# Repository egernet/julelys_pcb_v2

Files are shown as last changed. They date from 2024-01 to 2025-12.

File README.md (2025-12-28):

# Julelys PCB v3

HAT (Hardware Attached on Top) til Orange Pi Zero 2 til styring af adresserbare SK6812 RGBW LED-strips.

## System Oversigt

```
Orange Pi Zero 2 ──► Julelys HAT ──► 8×55 SK6812 LED Matrix (440 LEDs)
        │                 │
        │ SPI @ 2.5 Mbps  │
        ▼                 ▼
  julelys_manager    ESP32-C3 (SPI slave)
                          │
                          ▼
                    74HC4051 MUX + Level Shifters
                          │
                          ▼
                    8x JST outputs
```

## Relaterede Repositories

| Repository | Beskrivelse |
|---|---|
| [julelys_manager](https://github.com/egernet/julelys_manager) | Swift CLI + MCP server til LED-styring |
| [julelys_esp32](https://github.com/egernet/julelys_esp32/tree/feature/Hat) | ESP-IDF firmware (feature/Hat branch) |

## Features

- **ESP32-C3-WROOM-02** som SPI slave med RMT LED driver
- **8 LED-kanaler** via 74HC4051 multiplexer
- **Level shifting** (3.3V → 5V) via 74AHCT1G125
- **USB-C** til strøm og programmering (CP2102N)
- **Auto-reset** kredsløb til nem flashing
- **AI-styring** via Model Context Protocol (MCP)

## Nøglekomponenter

| Komponent | Funktion |
|---|---|
| ESP32-C3-WROOM-02 | Hoved-MCU, SPI slave |
| CP2102N | USB-UART bridge |
| AMS1117-3.3 | 5V → 3.3V LDO |
| 74HC4051 | 8-kanal analog multiplexer |
| 74AHCT1G125 ×4 | Level shifters |

## Connectors

| Reference | Type | Funktion |
|---|---|---|
| J1 | 2×13 Pin Socket | Orange Pi GPIO header |
| J4-J11 | JST B3B-XH-A ×8 | LED strip outputs |
| P1 | USB-C | Strøm + programmering |
| V_IN1 | Skrueterminal | Ekstern 5V |

## KiCad Filer

- `Julelys.kicad_pcb` - PCB layout
- `Julelys.kicad_sch` - Hovedskema
- `esp32.kicad_sch` - ESP32 subskema
- `power.kicad_sch` - Strømforsyning
- `untitled.kicad_sch` - USB-C og connectors

## Produktion

Produktionsfiler genereres til `production/`:
- Gerber filer (zipped)
- `bom.csv` - Stykliste
- `positions.csv` - Pick and place

## Licens

MIT

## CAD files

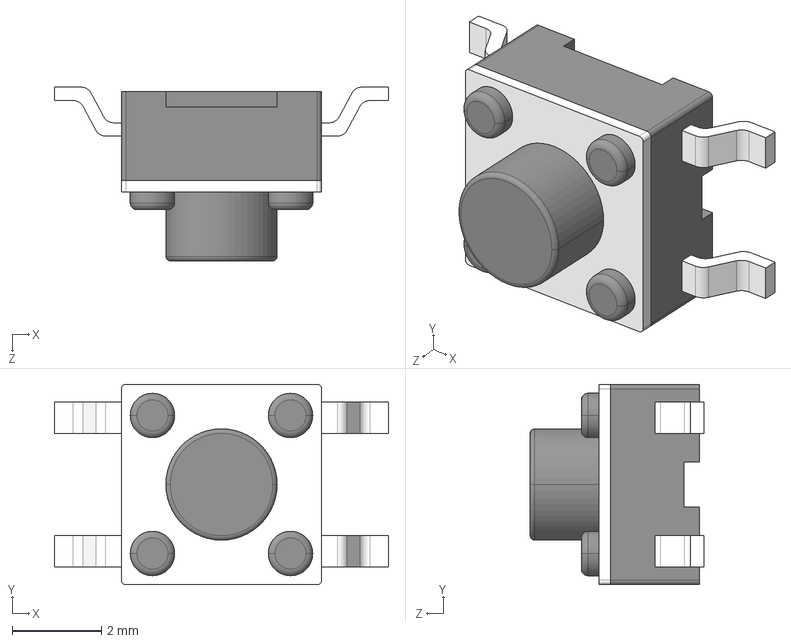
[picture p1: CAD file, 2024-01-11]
3D/TL3305AF260QG.stp
7.50 x 4.50 x 3.90 mm

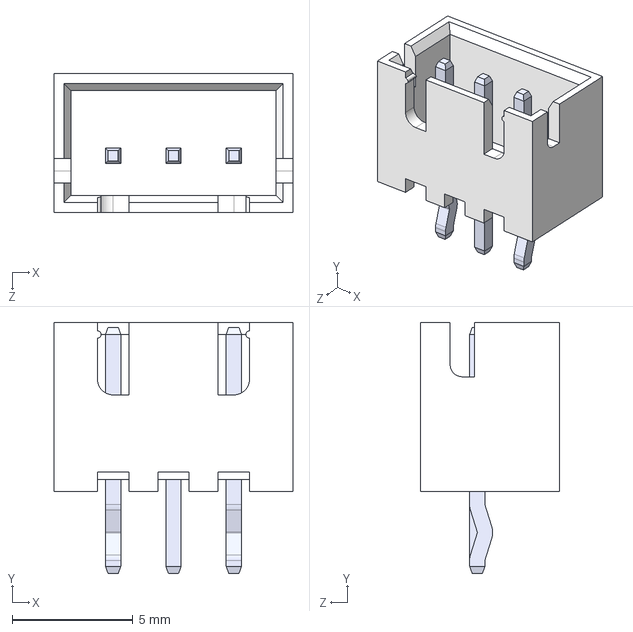
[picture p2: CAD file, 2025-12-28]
B3B_XH_A/B3B-XH-A.step
9.90 x 10.4 x 5.75 mm

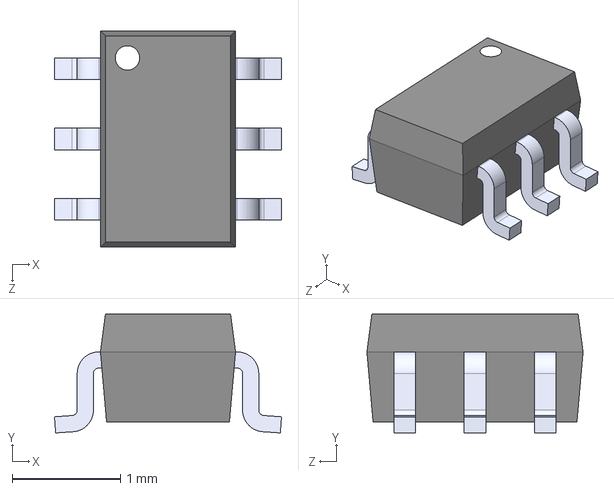
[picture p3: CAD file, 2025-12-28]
BC847BDW1T1G/BC847BDW1T1G.step
2.10 x 1.10 x 2.00 mm

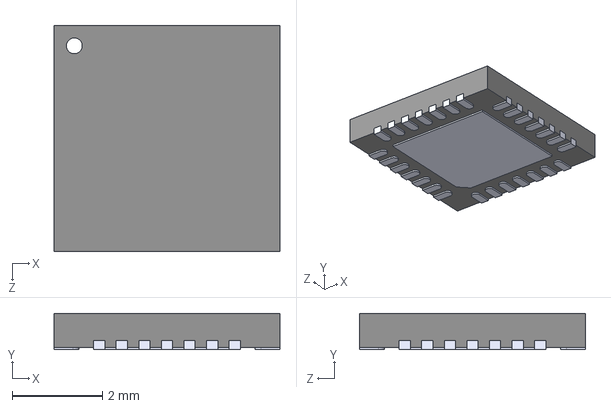
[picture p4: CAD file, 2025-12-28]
CP2102N_A02_GQFN28/CP2102N-A02-GQFN28.step
5.00 x 0.8 x 5.00 mm

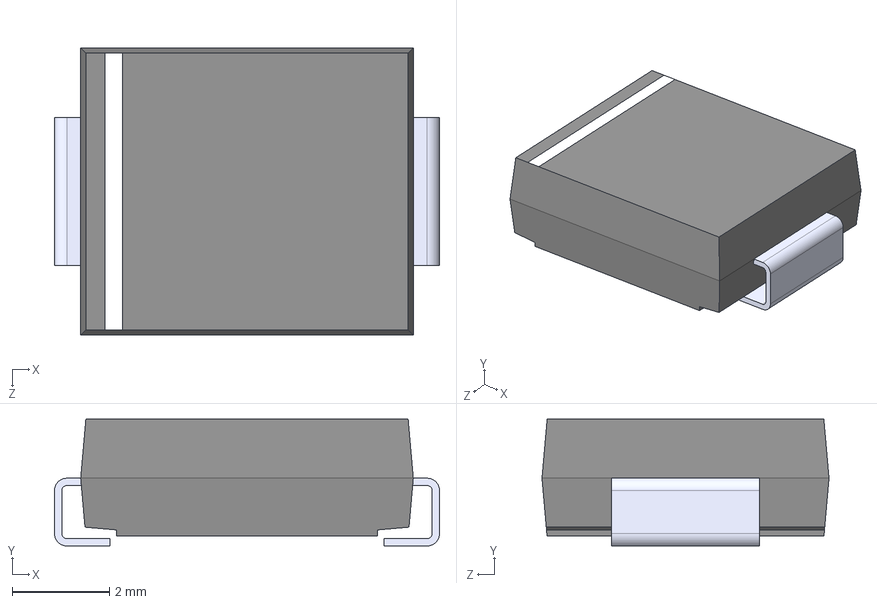
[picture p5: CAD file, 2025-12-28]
SS34_E3_57T/SS34-E3_57T.step
7.94 x 2.62 x 5.92 mm

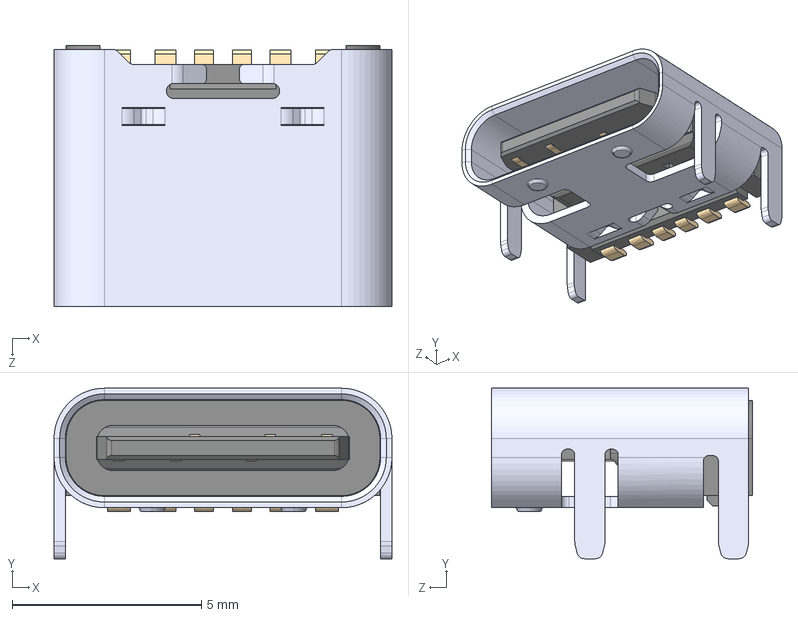
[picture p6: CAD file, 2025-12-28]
USB4125_GF_A/USB4125-GF-A_REVA2.step
8.94 x 4.51 x 6.90 mm

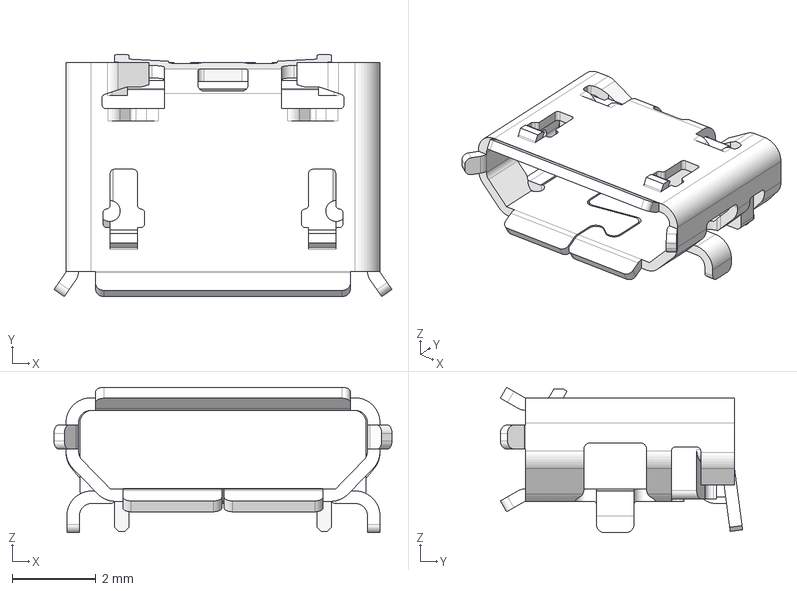
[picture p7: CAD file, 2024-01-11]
ZX62D_B_5PA8/ZX62D-B-5PA8.step
8.09 x 5.80 x 3.48 mm

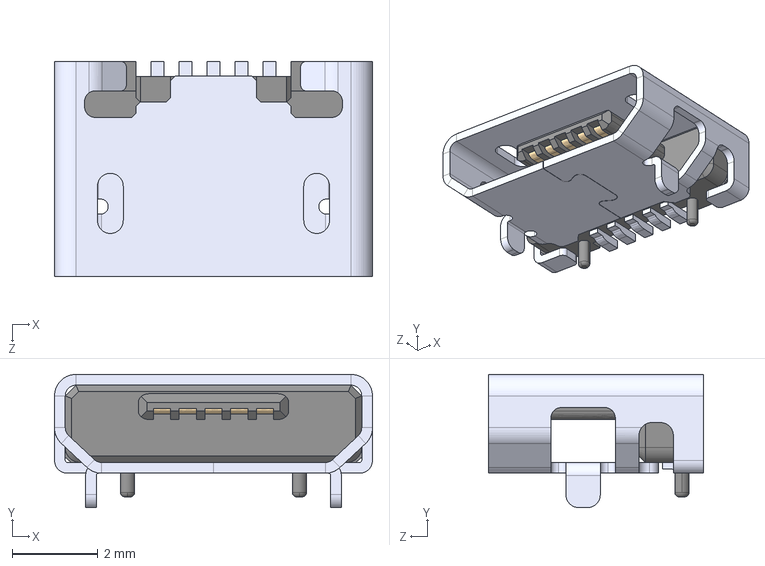
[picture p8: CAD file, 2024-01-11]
3D/U254-051T-4BH83-F1S--3DModel-STEP-510211.STEP
7.40 x 3.10 x 5.00 mm

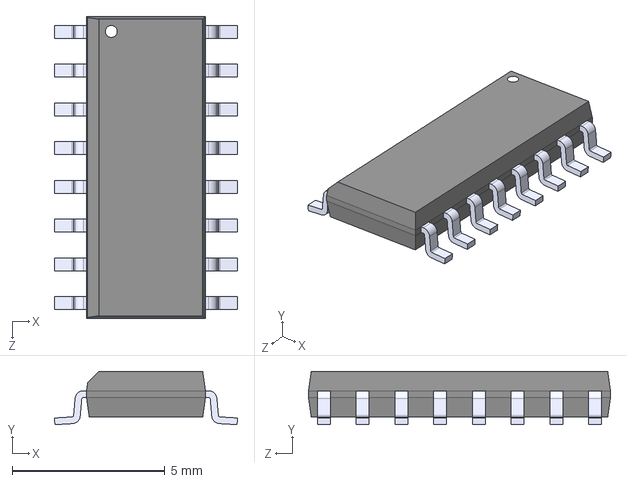
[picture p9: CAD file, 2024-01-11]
3D/74HC4051D.STEP
6.00 x 1.75 x 9.90 mm

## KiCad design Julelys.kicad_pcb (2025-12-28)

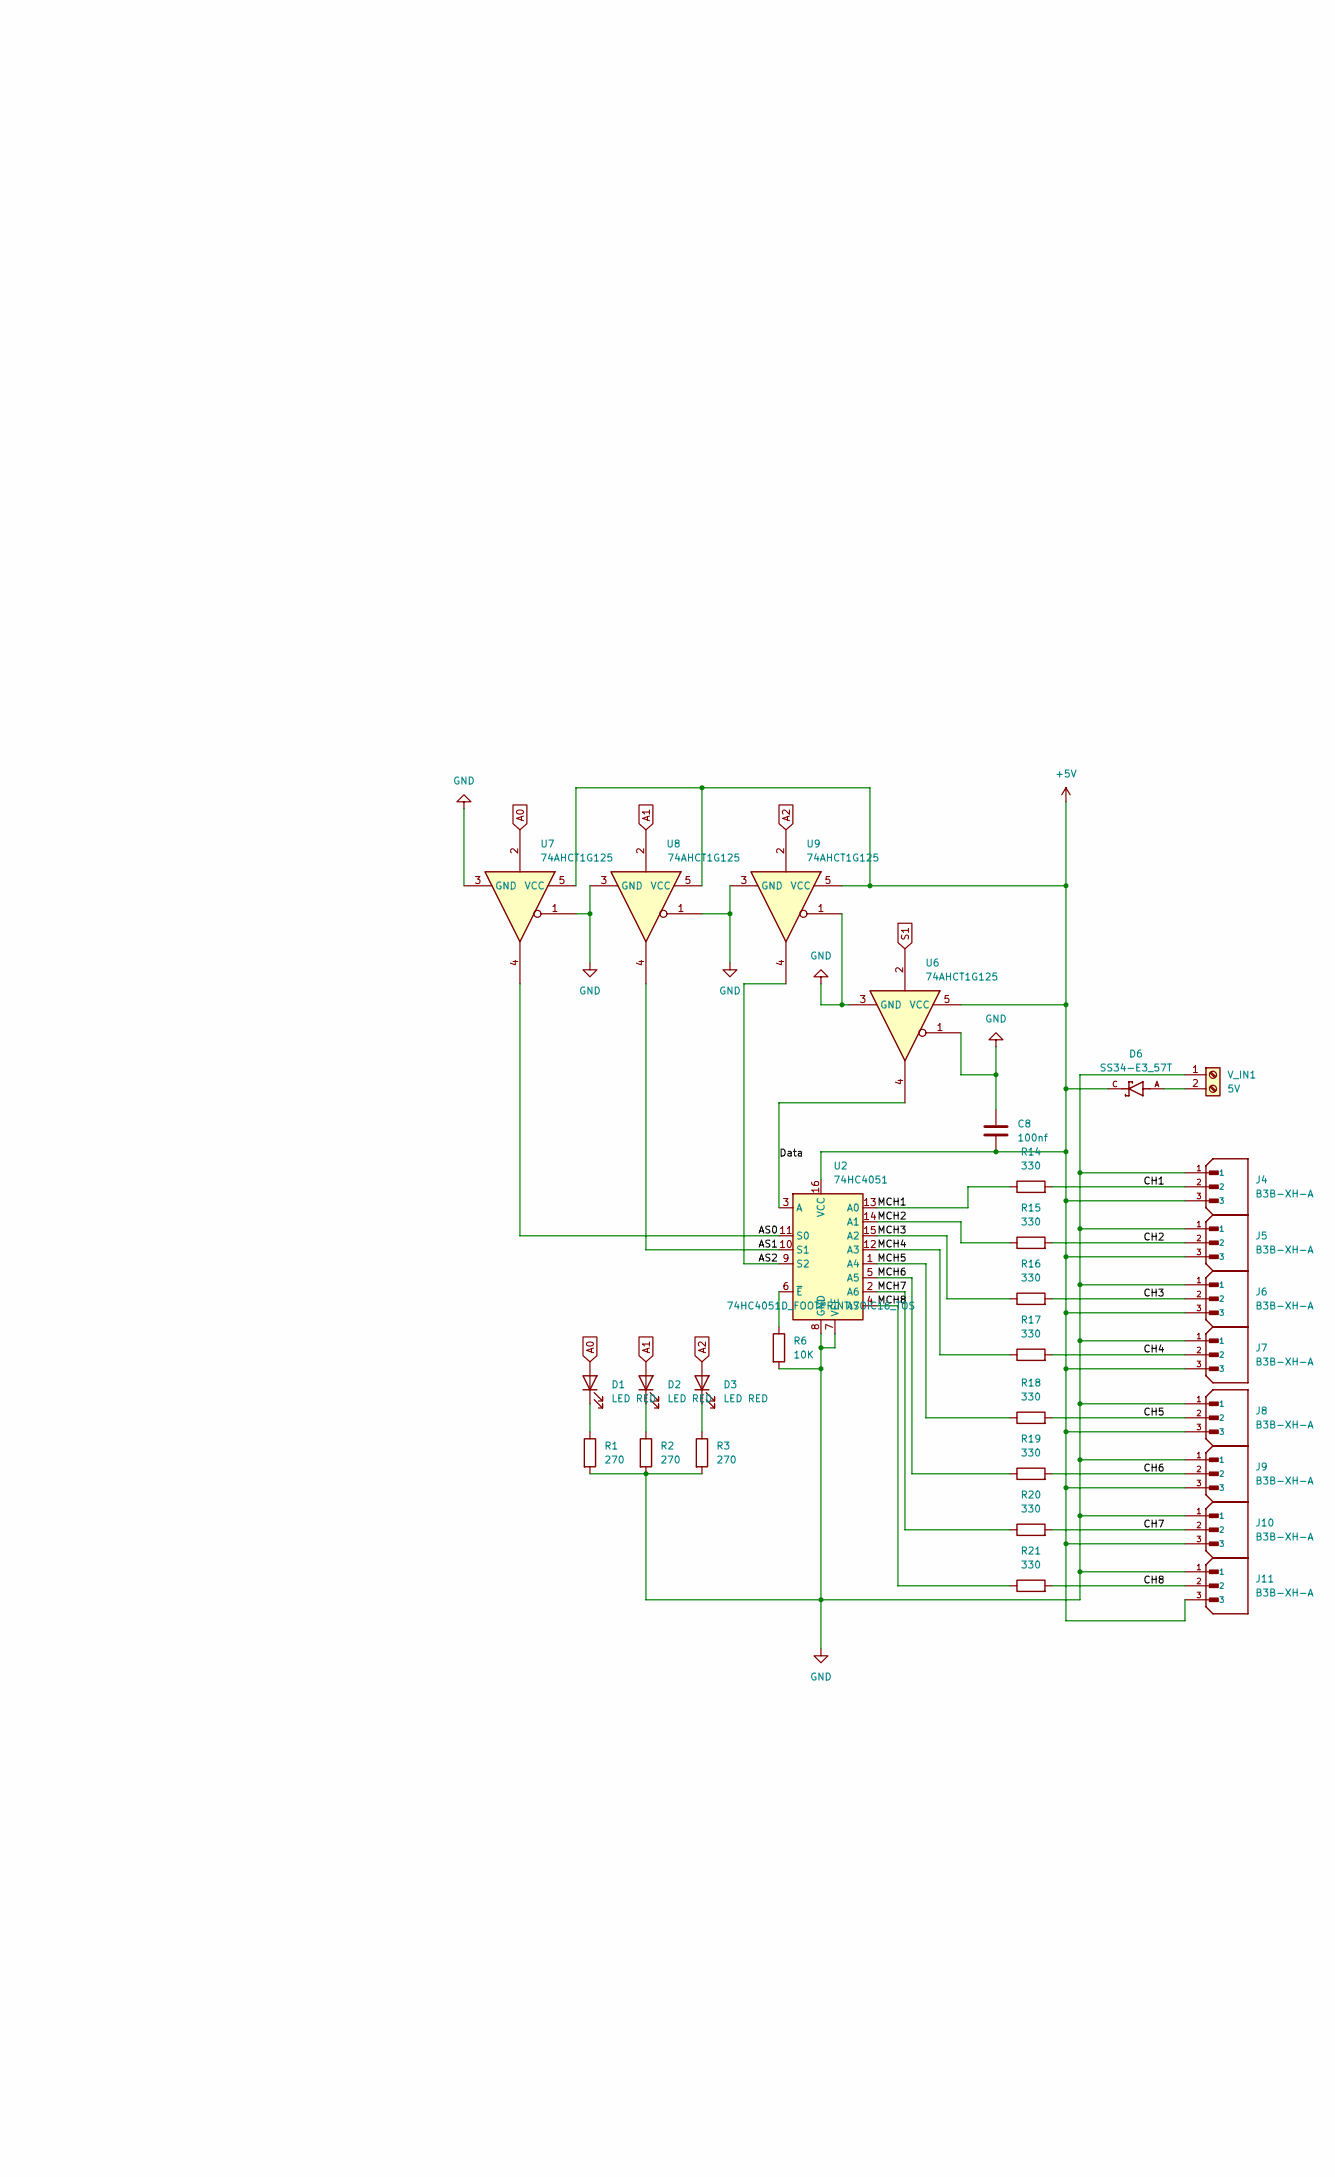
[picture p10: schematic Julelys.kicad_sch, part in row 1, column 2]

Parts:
C8: 100nf; R_0603_1608Metric
D1, D2, D3: LED RED; LED_0805_2012Metric
D6: SS34-E3_57T; DIOM7959X262N; PARTREV N/A
J4, J5, J6, J7, J8, J9, J10, J11: B3B-XH-A; JST_B3B-XH-A; PARTREV 7/4/21
R1, R2, R3: 270; R_0603_1608Metric
R6: 10K; R_0603_1608Metric
R14, R15, R16, R17, R18, R19, R20, R21: 330; R_0603_1608Metric
U2: 74HC4051; SOIC16_TOS
U6, U7, U8, U9: 74AHCT1G125; SOT-353_SC-70-5
V_IN1: 5V; TerminalBlock_Altech_AK300-2_P5.00mm

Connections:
+5V: C8.2, D6.C, J4.3, J5.3, J6.3, J7.3, J8.3, J9.3, J10.3, J11.3, U2.16 (VCC), U6.5 (VCC), U7.5 (VCC), U8.5 (VCC), U9.5 (VCC); also elsewhere on the board
/AS0: U2.11 (S0), U7.4
/AS1: U2.10 (S1), U8.4
/AS2: U2.9 (S2), U9.4
/CH1: J4.2, R14.2
/CH2: J5.2, R15.2
/CH3: J6.2, R16.2
/CH4: J7.2, R17.2
/CH5: J8.2, R18.2
/CH6: J9.2, R19.2
/CH7: J10.2, R20.2
/CH8: J11.2, R21.2
/Data: U2.3 (A), U6.4
/MCH1: R14.1, U2.13 (A0)
/MCH2: R15.1, U2.14 (A1)
/MCH3: R16.1, U2.15 (A2)
/MCH4: R17.1, U2.12 (A3)
/MCH5: R18.1, U2.1 (A4)
/MCH6: R19.1, U2.5 (A5)
/MCH7: R20.1, U2.2 (A6)
/MCH8: R21.1, U2.4 (A7)
A0: D1.2 (A), U7.2; also elsewhere on the board
A1: D2.2 (A), U8.2; also elsewhere on the board
A2: D3.2 (A), U9.2; also elsewhere on the board
GND: C8.1, J4.1, J5.1, J6.1, J7.1, J8.1, J9.1, J10.1, J11.1, R1.2, R2.2, R3.2, R6.2, U2.7 (VEE), U2.8 (GND), U6.1, U6.3 (GND), U7.1, U7.3 (GND), U8.1, U8.3 (GND), U9.1, U9.3 (GND), V_IN1.1; also elsewhere on the board
IO7: U6.2; also elsewhere on the board
unnamed: D1.1 (K), R1.1
unnamed: D2.1 (K), R2.1
unnamed: D3.1 (K), R3.1
unnamed: R6.1, U2.6 (~E)
unnamed: D6.A, V_IN1.2

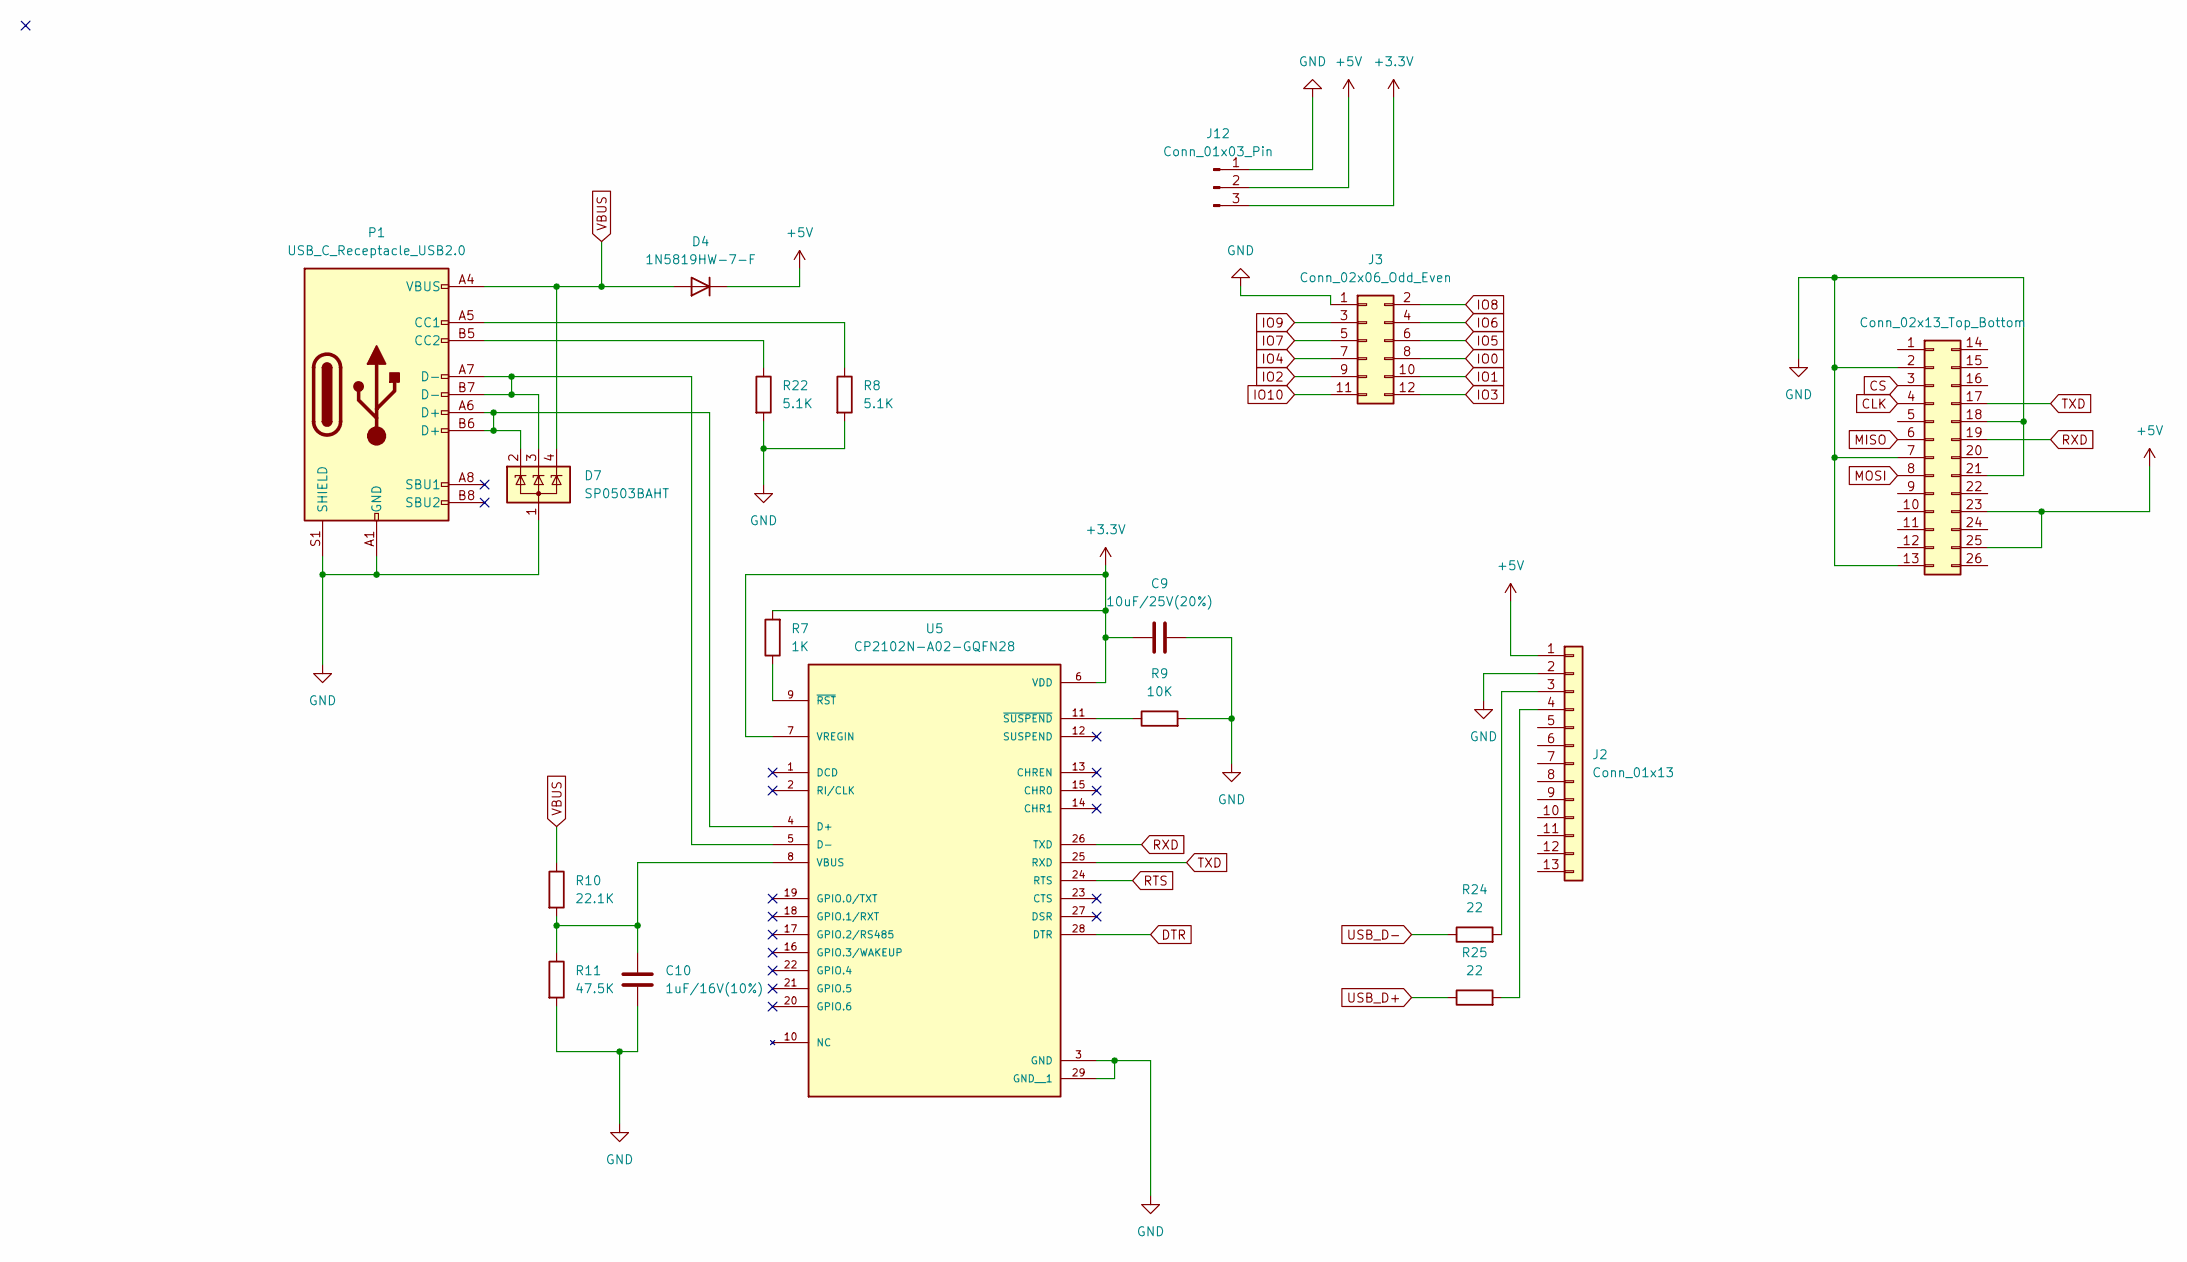
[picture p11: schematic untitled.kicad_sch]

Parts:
C9: 10uF/25V(20%); C_0603_1608Metric
C10: 1uF/16V(10%); C_0603_1608Metric
D4: 1N5819HW-7-F; D_SOD-123
D7: SP0503BAHT; SOT-143
J1: Conn_02x13_Top_Bottom; PinSocket_2x13_P2.54mm_Vertical
J2: Conn_01x13; PinSocket_1x13_P2.54mm_Vertical
J3: Conn_02x06_Odd_Even; PinHeader_2x06_P2.54mm_Vertical
J12: Conn_01x03_Pin; PinHeader_1x03_P2.54mm_Vertical
P1: USB_C_Receptacle_USB2.0; USB_C_Receptacle_HRO_TYPE-C-31-M-12
R7: 1K; R_0603_1608Metric
R8, R22: 5.1K; R_0603_1608Metric
R9: 10K; R_0603_1608Metric
R10: 22.1K; R_0603_1608Metric
R11: 47.5K; R_0603_1608Metric
R24, R25: 22; R_0603_1608Metric
U5: CP2102N-A02-GQFN28; QFN50P500X500X80-29N; PARTREV 1.5

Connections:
+3.3V: C9.1, J12.3, R7.2, U5.6 (VDD), U5.7 (VREGIN); also elsewhere on the board
+5V: D4.1 (K), J1.23, J1.25, J2.1, J12.2; also elsewhere on the board
A0: J3.7; also elsewhere on the board
A1: J3.6; also elsewhere on the board
A2: J3.2; also elsewhere on the board
CLK: J1.4, J3.12; also elsewhere on the board
CS: J1.3, J3.11; also elsewhere on the board
DTR: U5.28 (DTR); also elsewhere on the board
GND: C9.2, C10.2, D7.1 (A), J1.2, J1.7, J1.13, J1.18, J1.21, J2.2, J3.1, J12.1, P1.A1 (GND), P1.A12 (GND), P1.B1 (GND), P1.B12 (GND), P1.S1 (SHIELD), R8.2, R9.2, R11.2, R22.2, U5.3 (GND), U5.29 (GND__1); also elsewhere on the board
IO0: J3.8; also elsewhere on the board
IO1: J3.10; also elsewhere on the board
IO2: J1.6, J3.9; also elsewhere on the board
IO6: J1.8, J3.4; also elsewhere on the board
IO7: J3.5; also elsewhere on the board
IO9: J3.3; also elsewhere on the board
unnamed: J2.3, R24.2
unnamed: J2.4, R25.2
unnamed: P1.A5 (CC1), R8.1
unnamed: P1.B5 (CC2), R22.1
unnamed: D7.2 (K), P1.A6 (D+), P1.B6 (D+), U5.4 (D+)
unnamed: D7.3 (K), P1.A7 (D-), P1.B7 (D-), U5.5 (D-)
unnamed: C10.1, R10.2, R11.1, U5.8 (VBUS)
unnamed: R7.1, U5.9 (~RST)
unnamed: R9.1, U5.11 (~SUSPEND)
RTS: U5.24 (RTS); also elsewhere on the board
RXD: J1.19, U5.26 (TXD); also elsewhere on the board
TXD: J1.17, U5.25 (RXD); also elsewhere on the board
USB_D+: R25.1; also elsewhere on the board
USB_D-: R24.1; also elsewhere on the board
VBUS: D4.2 (A), D7.4 (K), P1.A4 (VBUS), P1.A9 (VBUS), P1.B4 (VBUS), P1.B9 (VBUS), R10.1

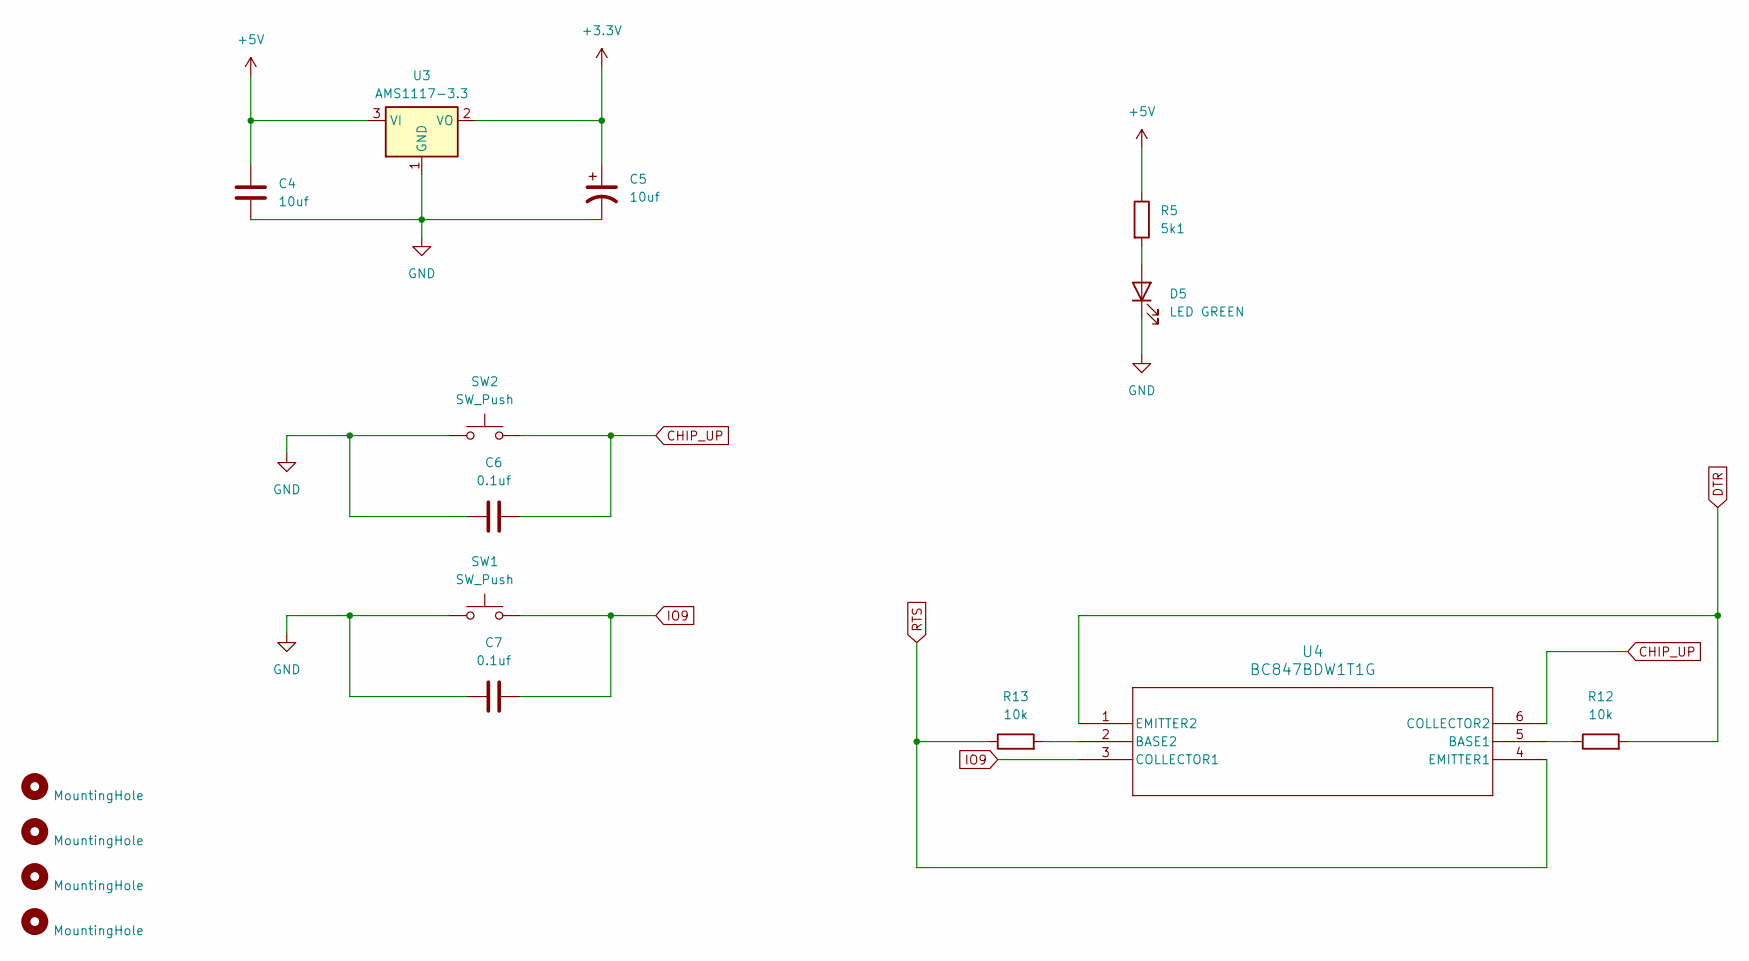
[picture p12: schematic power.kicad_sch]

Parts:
C4, C5: 10uf; C_0603_1608Metric
C6, C7: 0.1uf; C_0603_1608Metric
D5: LED GREEN; LED_0805_2012Metric
H1, H2, H3, H4: MountingHole; MountingHole_3.2mm_M3
R5: 5k1; R_0603_1608Metric
R12, R13: 10k; R_0603_1608Metric
SW1, SW2: SW_Push; SW_SPST_TL3305A
U3: AMS1117-3.3; SOT-223-3_TabPin2
U4: BC847BDW1T1G; SOT65P210X110-6N

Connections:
+3.3V: C5.1, U3.2 (VO); also elsewhere on the board
+5V: C4.1, R5.1, U3.3 (VI); also elsewhere on the board
CHIP_UP: C6.2, SW2.2, U4.6 (COLLECTOR2); also elsewhere on the board
DTR: R12.2, U4.1 (EMITTER2); also elsewhere on the board
GND: C4.2, C5.2, C6.1, C7.1, D5.1 (K), SW1.1, SW2.1, U3.1 (GND); also elsewhere on the board
IO9: C7.2, SW1.2, U4.3 (COLLECTOR1); also elsewhere on the board
unnamed: D5.2 (A), R5.2
unnamed: R12.1, U4.5 (BASE1)
unnamed: R13.2, U4.2 (BASE2)
RTS: R13.1, U4.4 (EMITTER1); also elsewhere on the board

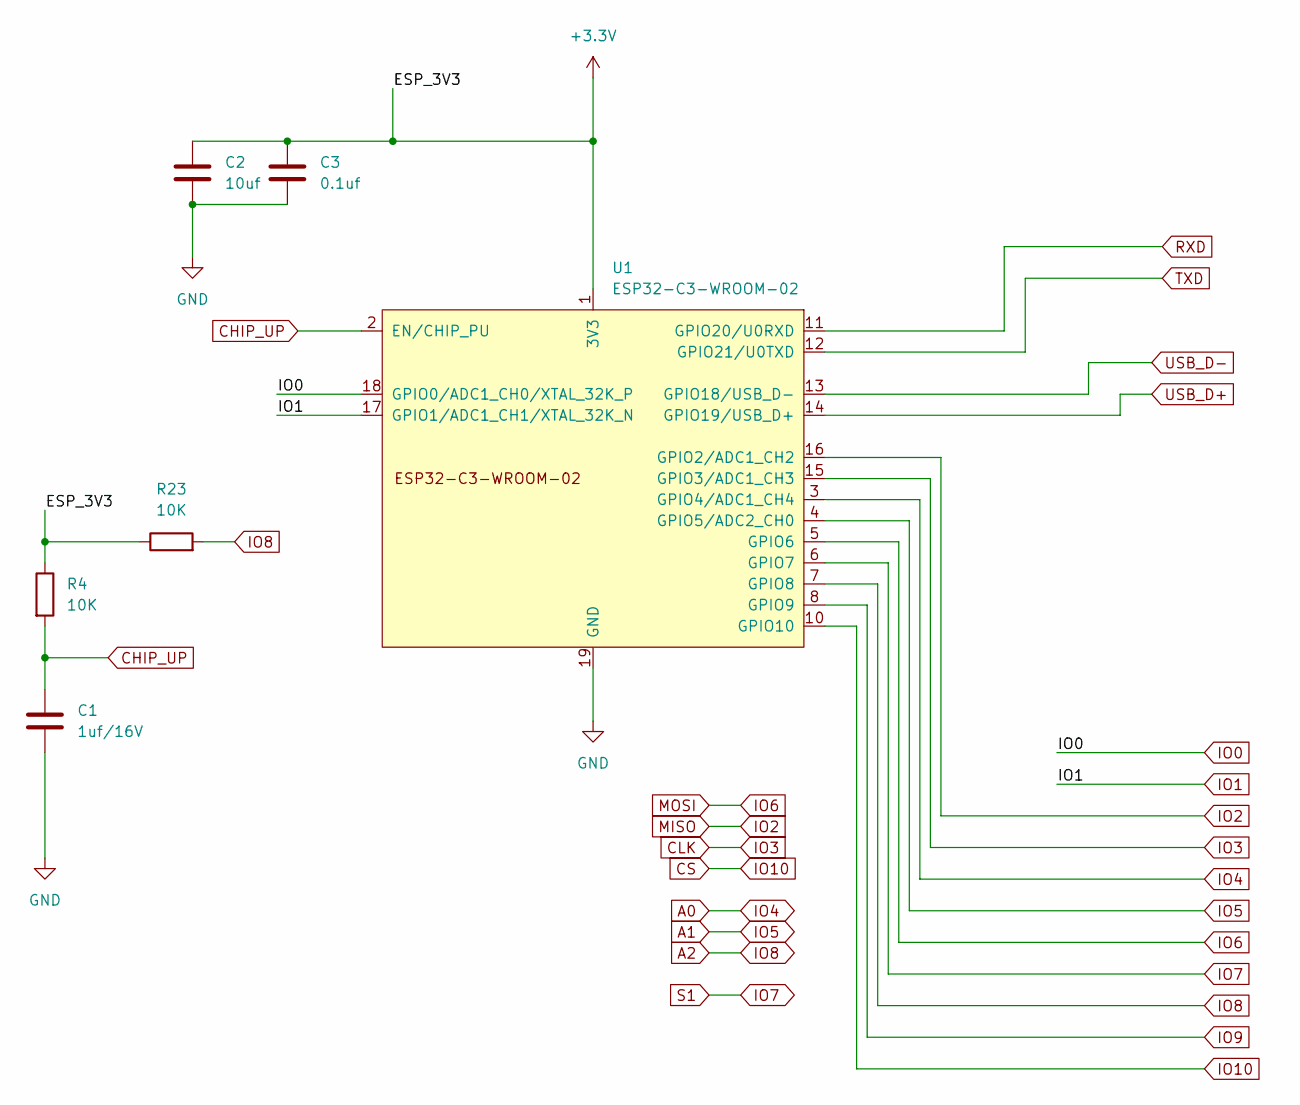
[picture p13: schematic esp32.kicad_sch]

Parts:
C1: 1uf/16V; C_0603_1608Metric
C2: 10uf; C_0603_1608Metric
C3: 0.1uf; C_0603_1608Metric
R4, R23: 10K; R_0603_1608Metric
U1: ESP32-C3-WROOM-02

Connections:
+3.3V: C2.1, C3.1, R4.1, R23.1, U1.1 (3V3); also elsewhere on the board
A0: U1.3 (GPIO4/ADC1_CH4); also elsewhere on the board
A1: U1.4 (GPIO5/ADC2_CH0); also elsewhere on the board
A2: R23.2, U1.7 (GPIO8); also elsewhere on the board
CHIP_UP: C1.1, R4.2, U1.2 (EN/CHIP_PU); also elsewhere on the board
CLK: U1.15 (GPIO3/ADC1_CH3); also elsewhere on the board
CS: U1.10 (GPIO10); also elsewhere on the board
GND: C1.2, C2.2, C3.2, U1.9 (GND), U1.19 (GND); also elsewhere on the board
IO0: U1.18 (GPIO0/ADC1_CH0/XTAL_32K_P); also elsewhere on the board
IO1: U1.17 (GPIO1/ADC1_CH1/XTAL_32K_N); also elsewhere on the board
IO2: U1.16 (GPIO2/ADC1_CH2); also elsewhere on the board
IO6: U1.5 (GPIO6); also elsewhere on the board
IO7: U1.6 (GPIO7); also elsewhere on the board
IO9: U1.8 (GPIO9); also elsewhere on the board
RXD: U1.11 (GPIO20/U0RXD); also elsewhere on the board
TXD: U1.12 (GPIO21/U0TXD); also elsewhere on the board
USB_D+: U1.14 (GPIO19/USB_D+); also elsewhere on the board
USB_D-: U1.13 (GPIO18/USB_D-); also elsewhere on the board

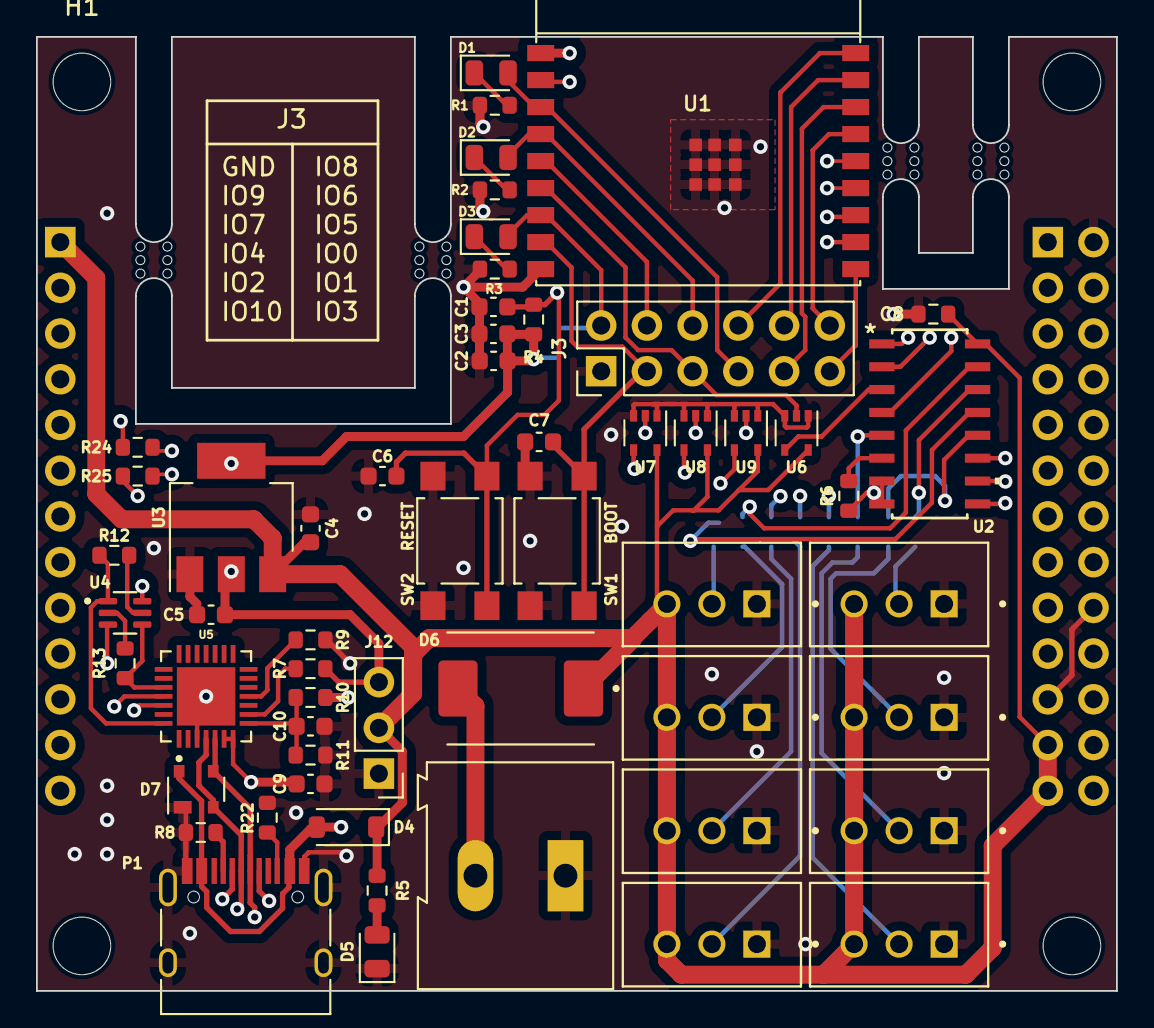
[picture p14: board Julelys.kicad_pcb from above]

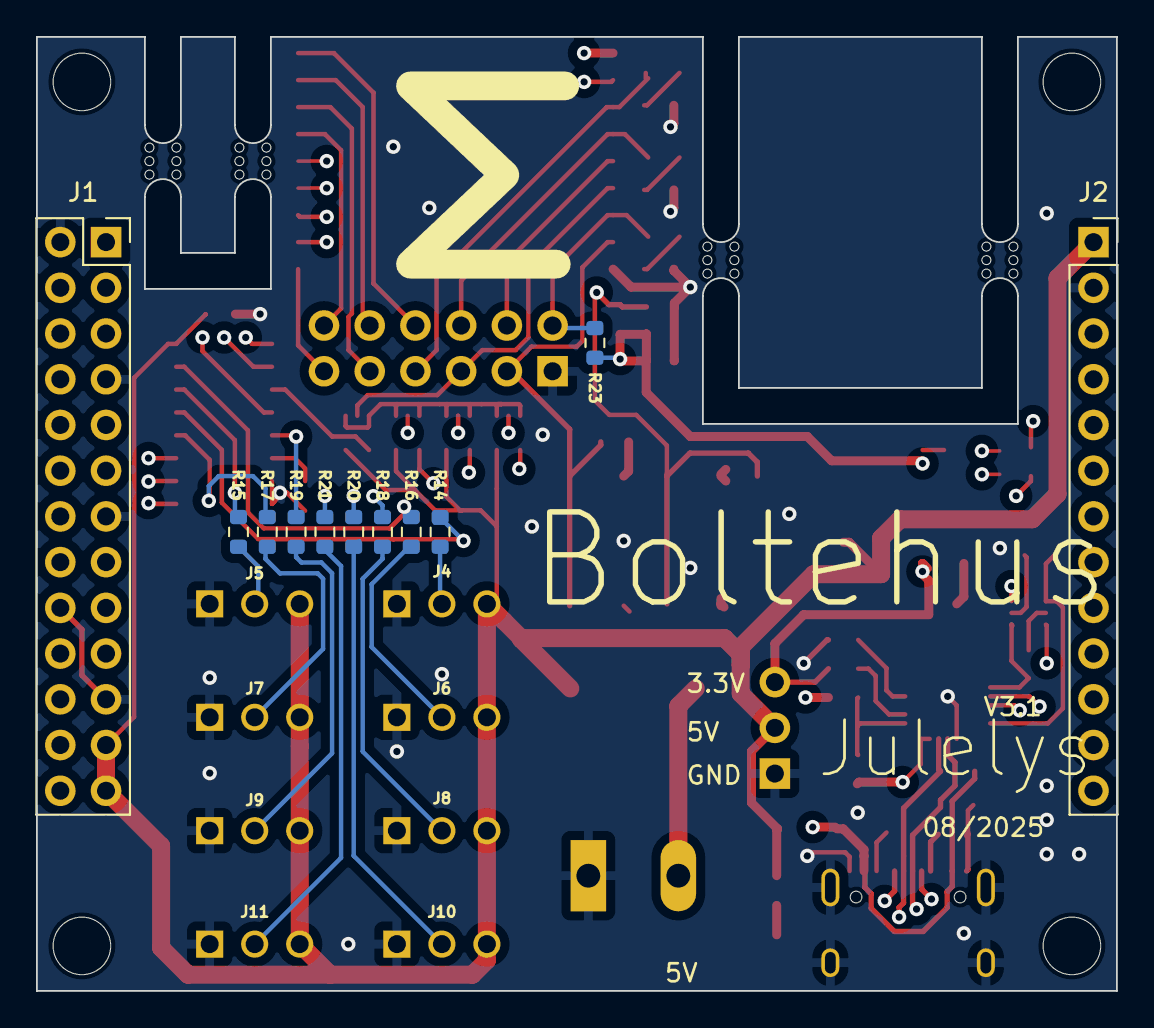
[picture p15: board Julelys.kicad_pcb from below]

Board: 4 copper layers, 60.0 x 53.0 mm, 75 parts (11 on the bottom side), 59 nets.

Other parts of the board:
mouse-bite-2mm-slot, mouse-bite-2mm-slot#2, mouse-bite-2mm-slot#3, mouse-bite-2mm-slot#4: VAL**; mouse-bite-2mm-slot

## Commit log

2024-01-11 Add files to PCB v2
    [74HC4051D.STEP, Julelys V2.kicad_pcb, Julelys V2.kicad_sch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]
2024-04-09 Update to V2.1
    [Julelys V2.kicad_sch, untitled.kicad_sch]
2024-04-09 clean up
    [Sample-BOM_JLCSMT.csv, Sample-BOM_JLCSMT.xlsx, bom.csv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]
2025-07-21 version 3
    [B3B-XH-A.step, BC847BDW1T1G.step, CP2102N-A02-GQFN28.step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]
2025-07-31 fix bugs
    [Julelys V2.kicad_pcb]
2025-08-05 Update to v3.1
    [Julelys V2.kicad_pcb, Julelys V2.kicad_sch, esp32.kicad_sch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]
2025-08-30 Small update
    [Julelys V2.kicad_pcb]
